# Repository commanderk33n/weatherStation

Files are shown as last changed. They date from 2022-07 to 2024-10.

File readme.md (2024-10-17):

# Weather Station NodeMCU
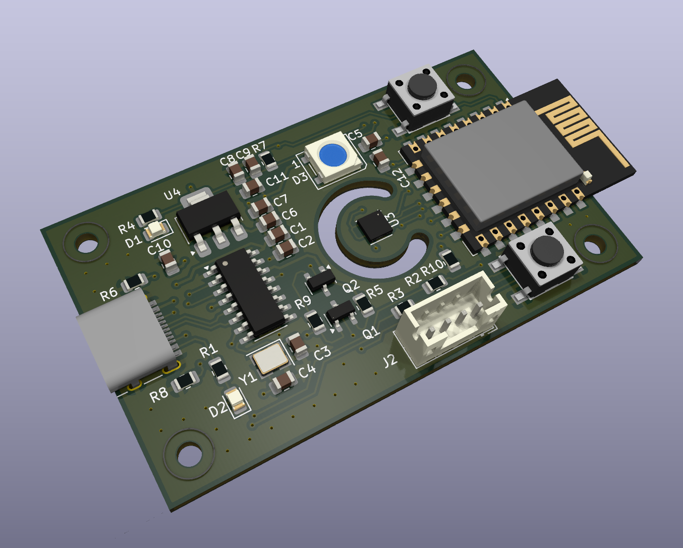
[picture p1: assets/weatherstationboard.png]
WeatherStationBoardV1.0

#### Usage:

after checkout:

- Download Arduino IDE
- Download ESP8266 Development Board and Driver File:
    - File->Preferences 'Additional Boards Manager URLs:
      - http://arduino.esp8266.com/stable/package_esp8266com_index.json
    - Download esp8266 with Boards Manager
- Install Libaries:
    - esp8266 weather
    - JSON Streaming
    - adafruit bme280
    - adafruit Unified sensor
    - oled lib from NodeMCU/lib
- Add your WIFI, Webserver and Database-Server info into weatherSationKeen.ino, esp-chart.php and post-data.php

#### Hardware used:
- NodeMCU ESP8266 (CP2102)
- GY-BME280 Sensormodul
- OLED-Display (SSH1106)
- RaspberryPi for Webserver (Nginx, MariaDB, PHP)

#### Pin Connection:
- NodeMCU ESP8266 <-----> OLED
    - 3.3V---VCC
    - GND---GND
    - D1---SCL
    - D2---SDA
- NodeMCU ESP8266<-----> BME280
    - 3.3V---VCC
    - GND---GND
    - D1---SCL
    - D2---SDA

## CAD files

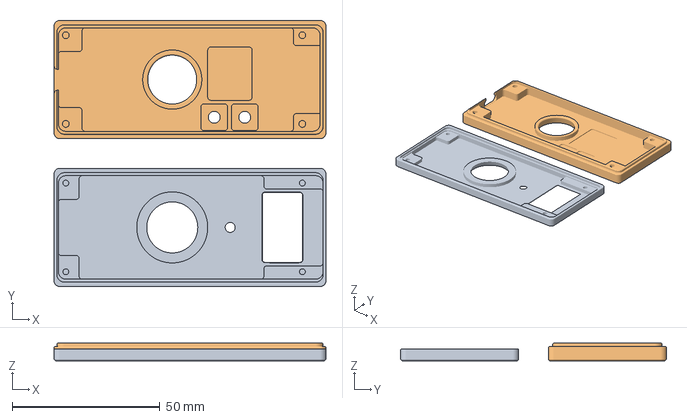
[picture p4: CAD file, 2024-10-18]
hardware/kicad/weatherStationBoard/WeatherStationBoard_REV01_CASE_BOT.3mf
92.0 x 90.0 x 6.00 mm
WeatherStationBoard_REV01_CASE_BOT.stl
WeatherStationBoard_REV01_CASE_TOP.stl

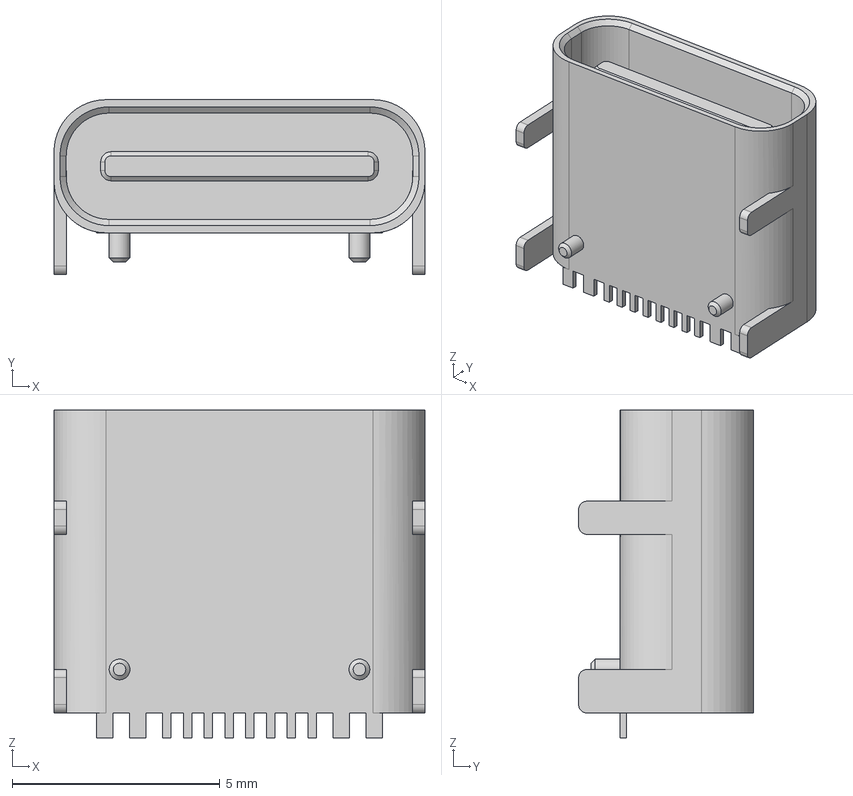
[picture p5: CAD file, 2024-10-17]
hardware/Parts/HRO TYPE-C-31-M-12/HRO TYPE-C-31-M-12.step
8.94 x 4.21 x 7.90 mm

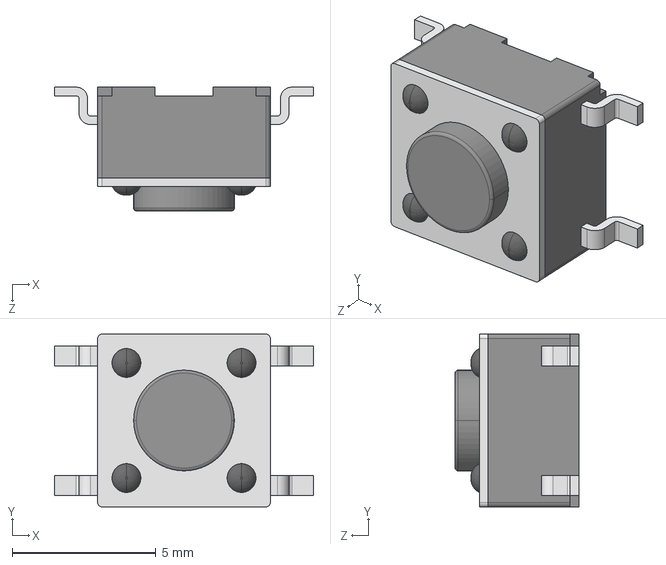
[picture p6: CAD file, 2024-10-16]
hardware/Parts/PTS645SM43SMTR92LFS/PTS645SM43SMTR92LFS.stp
9.00 x 6.00 x 4.30 mm

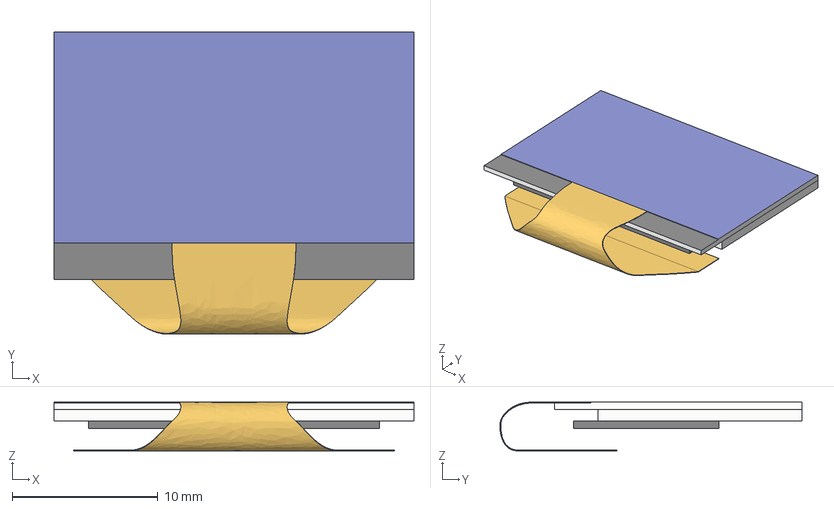
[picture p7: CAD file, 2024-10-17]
hardware/Parts/SSD1306/Unbenannt-SSD1306_Screen.step
24.7 x 20.7 x 3.35 mm
screen
screen001
screen002
flat_cable

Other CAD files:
hardware/kicad/weatherStationBoard/Gerber/weatherStationBoard-B_Silkscreen.dxf
hardware/kicad/weatherStationBoard/Gerber/weatherStationBoard-F_Silkscreen.dxf

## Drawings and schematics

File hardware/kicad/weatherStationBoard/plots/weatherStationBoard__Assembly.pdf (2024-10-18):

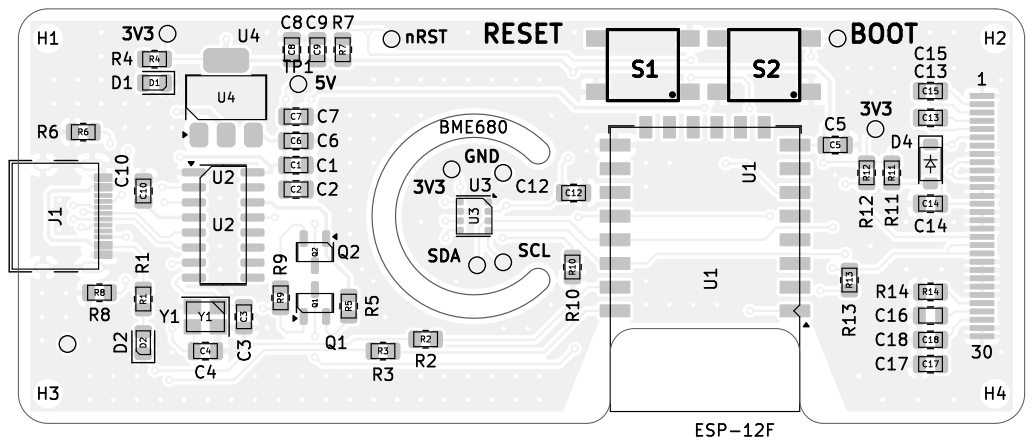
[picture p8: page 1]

Id: 1/1 Title: File: weatherStationBoard.kicad_pcb Sheet:

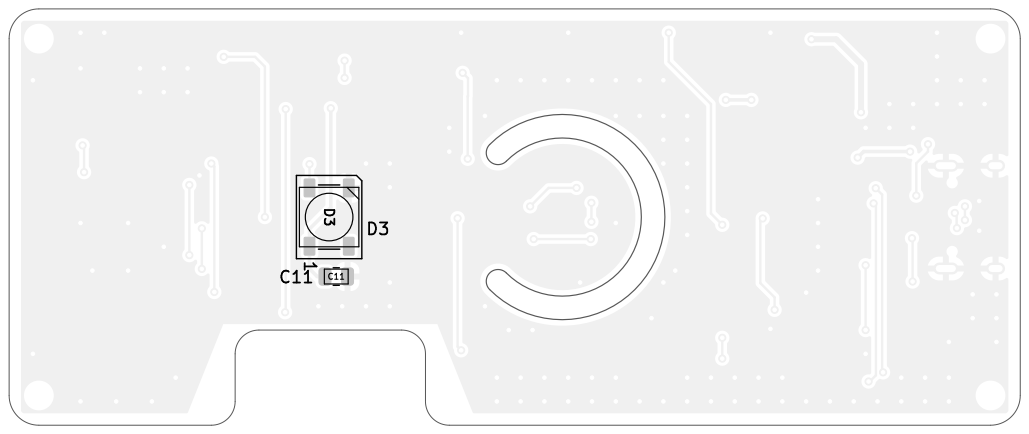
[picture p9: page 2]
D Date: KiCad; E.D.A. 8.0.6 Size: A4; Rev:

Id: 1/1 Title: File: weatherStationBoard.kicad_pcb Sheet:

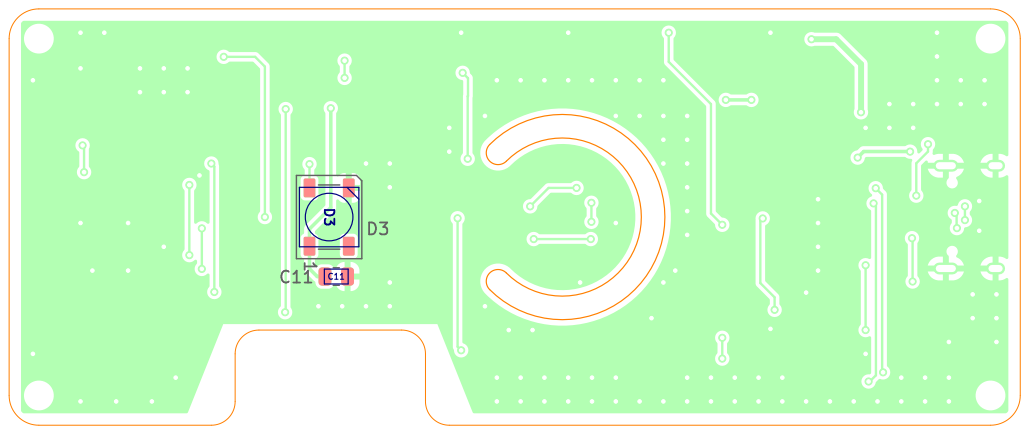
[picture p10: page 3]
D Date: KiCad; E.D.A. 8.0.6 Size: A4; Rev:

Id: 1/1 Title: File: weatherStationBoard.kicad_pcb Sheet:

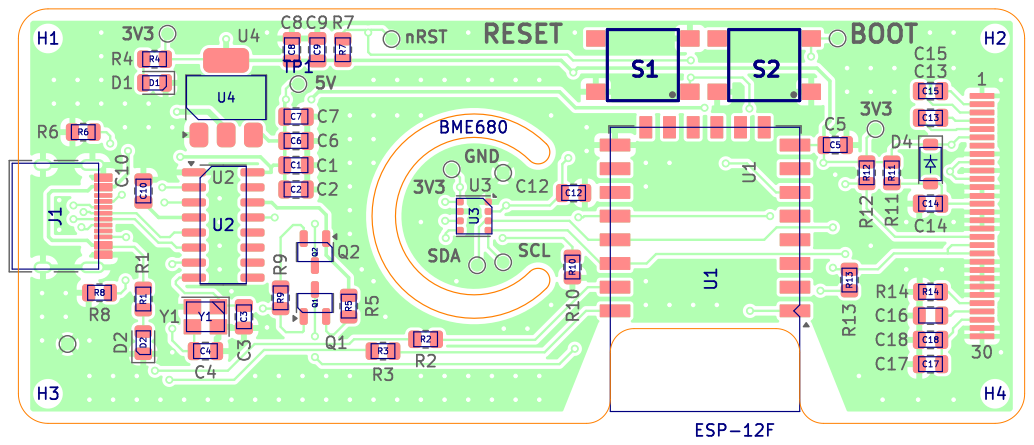
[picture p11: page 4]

Id: 1/1 Title: File: weatherStationBoard.kicad_pcb Sheet:

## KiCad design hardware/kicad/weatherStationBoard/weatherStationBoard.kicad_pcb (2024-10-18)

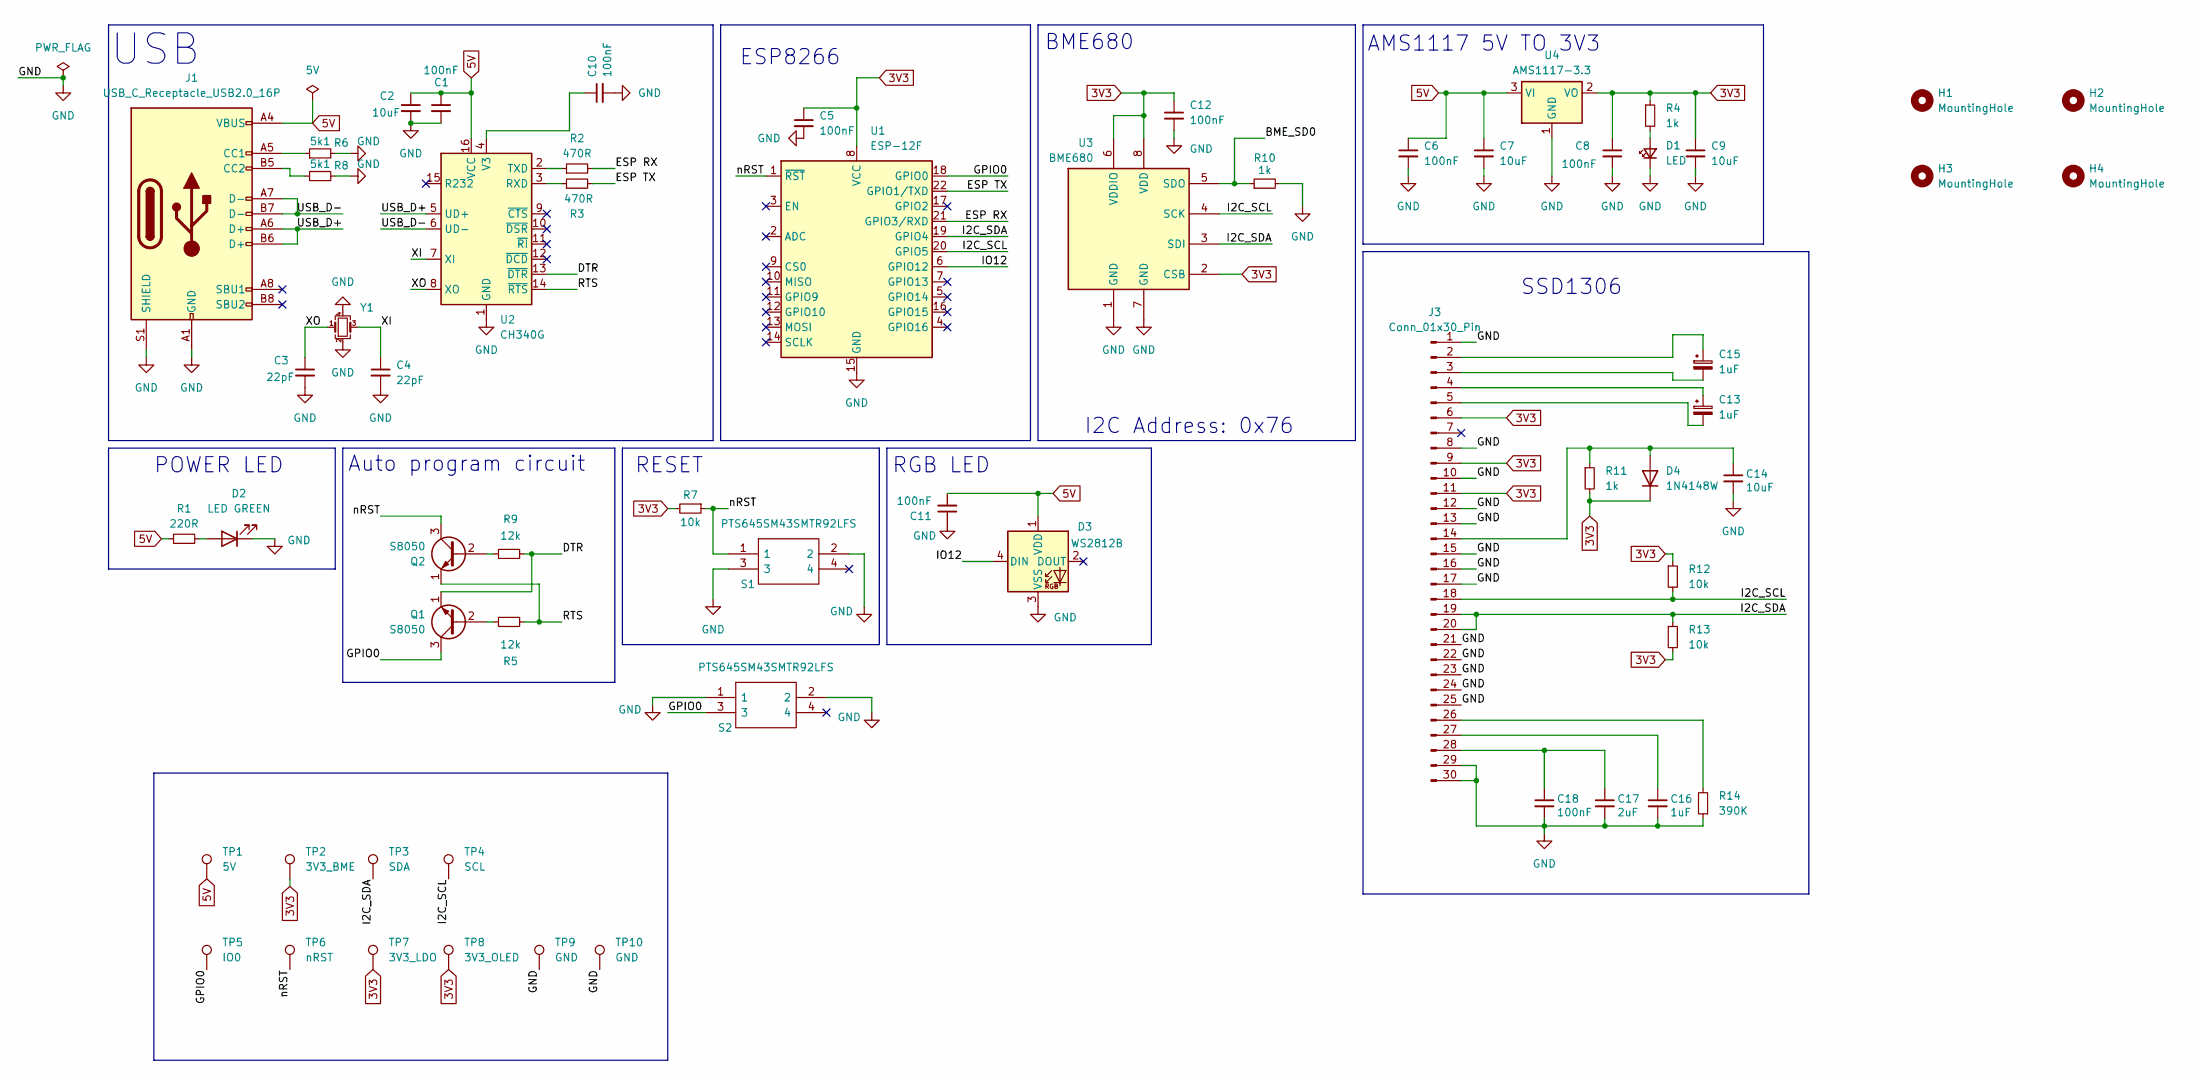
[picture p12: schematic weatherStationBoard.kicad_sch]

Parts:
C1, C5, C6, C8, C10, C11, C12, C18: 100nF; C_0805_2012Metric
C2, C7, C9, C14: 10uF; C_0805_2012Metric
C3, C4: 22pF; C_0805_2012Metric
C13, C15, C16: 1uF; C_0805_2012Metric
C17: 2uF; C_0805_2012Metric
D1: LED; LED_0805_2012Metric
D2: LED GREEN; LED_0805_2012Metric
D3: WS2812B; LED_WS2812B_PLCC4_5.0x5.0mm_P3.2mm
D4: 1N4148W; D_SOD-123
H1, H2, H3, H4: MountingHole; MountingHole_2.2mm_M2
J1: USB_C_Receptacle_USB2.0_16P; USB_C_Receptacle_HRO_TYPE-C-31-M-12
J3: Conn_01x30_Pin; SSD1306_ribbon
Q1, Q2: S8050; SOT-23-3
R1: 220R; R_0805_2012Metric
R2, R3: 470R; R_0805_2012Metric
R4, R10, R11: 1k; R_0805_2012Metric
R5, R9: 12k; R_0805_2012Metric
R6, R8: 5k1; R_0805_2012Metric
R7, R12, R13: 10k; R_0805_2012Metric
R14: 390K; R_0805_2012Metric
S1, S2: PTS645SM43SMTR92LFS; PTS645_SMT_; Manufacturer_Part_Number PTS645SM43SMTR92LFS; Mouser Part Number 611-PTS645SM43SMTR92
TP1: 5V; TestPoint_Pad_D1.0mm
TP2: 3V3_BME; TestPoint_Pad_D1.0mm
TP3: SDA; TestPoint_Pad_D1.0mm
TP4: SCL; TestPoint_Pad_D1.0mm
TP5: IO0; TestPoint_Pad_D1.0mm
TP6: nRST; TestPoint_Pad_D1.0mm
TP7: 3V3_LDO; TestPoint_Pad_D1.0mm
TP8: 3V3_OLED; TestPoint_Pad_D1.0mm
TP9, TP10: GND; TestPoint_Pad_D1.0mm
U1: ESP-12F; ESP-12E
U2: CH340G; SOIC-16_3.9x9.9mm_P1.27mm
U3: BME680; Bosch_LGA-8_3x3mm_P0.8mm_ClockwisePinNumbering
U4: AMS1117-3.3; SOT-223-3_TabPin2
Y1: Crystal_GND24_Small; Crystal_SMD_3225-4Pin_3.2x2.5mm

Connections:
3V3: C5.1, C8.1, C9.1, C12.1, D4.1 (K), J3.6, J3.9, J3.11, R4.1, R7.2, R11.2, R12.1, R13.2, TP2.1, TP7.1, TP8.1, U1.8 (VCC), U3.2 (CSB), U3.6 (VDDIO), U3.8 (VDD), U4.2 (VO)
5V: C1.1, C2.1, C6.1, C7.1, C11.2, D3.1 (VDD), J1.A4 (VBUS), J1.A9 (VBUS), J1.B4 (VBUS), J1.B9 (VBUS), R1.1, TP1.1, U2.16 (VCC), U4.3 (VI)
/BME_SD0: R10.1, U3.5 (SDO)
/DTR: Q1.1 (E), R9.2, U2.13 (~DTR)
/ESP RX: R2.2, U1.21 (GPIO3/RXD)
/ESP TX: R3.2, U1.22 (GPIO1/TXD)
/GPIO0: Q1.3 (C), S2.3, TP5.1, U1.18 (GPIO0)
/I2C_SCL: J3.18, R12.2, TP4.1, U1.20 (GPIO5), U3.4 (SCK)
/I2C_SDA: J3.19, J3.20, R13.1, TP3.1, U1.19 (GPIO4), U3.3 (SDI)
/IO12: D3.4 (DIN), U1.6 (GPIO12)
/RTS: Q2.1 (E), R5.2, U2.14 (~RTS)
/USB_D+: J1.A6 (D+), J1.B6 (D+), U2.5 (UD+)
/USB_D-: J1.A7 (D-), J1.B7 (D-), U2.6 (UD-)
/XI: C4.1, U2.7 (XI), Y1.3
/XO: C3.1, U2.8 (XO), Y1.1
/nRST: Q2.3 (C), R7.1, S1.1, TP6.1, U1.1 (~RST)
GND: C1.2, C2.2, C3.2, C4.2, C5.2, C6.2, C7.2, C8.2, C9.2, C10.2, C11.1, C12.2, C14.2, C16.2, C17.2, C18.2, D1.1 (K), D2.1 (K), D3.3 (VSS), J1.A1 (GND), J1.A12 (GND), J1.B1 (GND), J1.B12 (GND), J1.S1 (SHIELD), J3.1, J3.8, J3.10, J3.12, J3.13, J3.15, J3.16, J3.17, J3.21, J3.22, J3.23, J3.24, J3.25, J3.29, J3.30, R6.2, R8.2, R10.2, R14.1, S1.2, S1.3, S2.1, S2.2, TP9.1, TP10.1, U1.15 (GND), U2.1 (GND), U3.1 (GND), U3.7 (GND), U4.1 (GND), Y1.2, Y1.4
unnamed: D1.2 (A), R4.2
unnamed: D2.2 (A), R1.2
unnamed: C14.1, D4.2 (A), J3.14, R11.1
unnamed: J1.A5 (CC1), R6.1
unnamed: J1.B5 (CC2), R8.1
unnamed: C15.1, J3.2
unnamed: C15.2, J3.3
unnamed: C13.1, J3.4
unnamed: C13.2, J3.5
unnamed: J3.26, R14.2
unnamed: C16.1, J3.27
unnamed: C17.1, C18.1, J3.28
unnamed: Q1.2 (B), R5.1
unnamed: Q2.2 (B), R9.1
unnamed: R3.1, U2.3 (RXD)
unnamed: R2.1, U2.2 (TXD)
unnamed: C10.1, U2.4 (V3)

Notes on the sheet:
I2C Address: 0x76
SSD1306
BME680
RGB LED
RESET
ESP8266
Auto program circuit
USB
AMS1117 5V TO 3V3
POWER LED

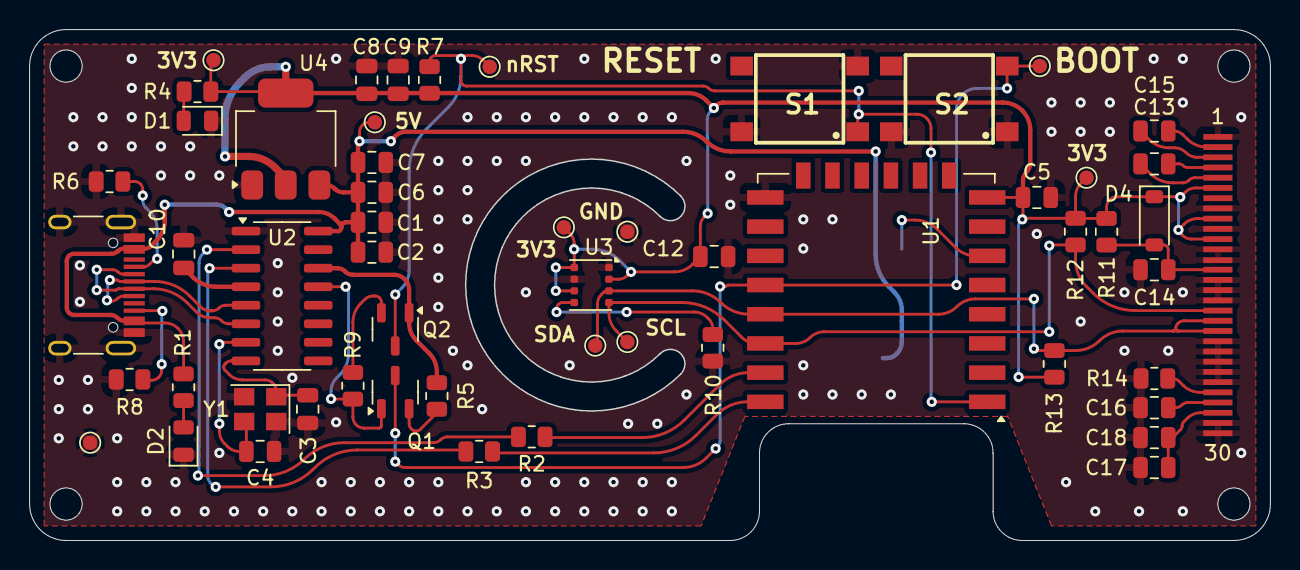
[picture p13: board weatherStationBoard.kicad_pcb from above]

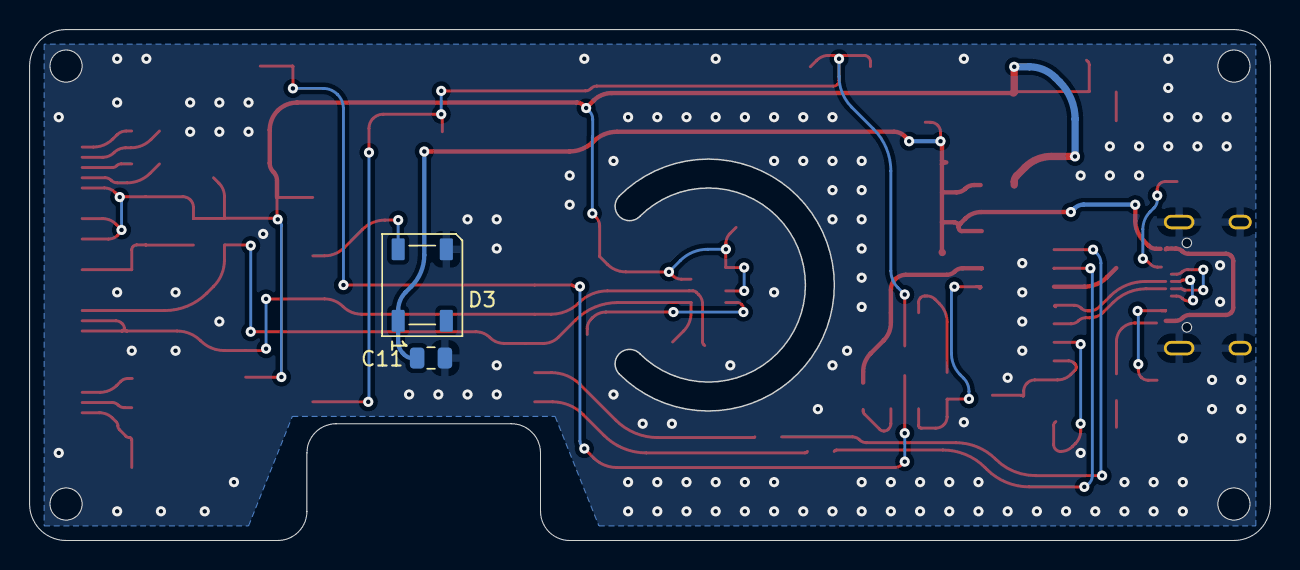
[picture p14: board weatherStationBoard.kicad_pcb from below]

Board: 4 copper layers, 85.0 x 35.0 mm, 61 parts (2 on the bottom side), 34 nets.

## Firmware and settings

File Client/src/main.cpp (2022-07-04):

/**
 * Keen's WeatherStation for NodeMCU
 * Display: SH1106Sensor: BME280
 * OpenWeatherMap API + http POST data to webserver
 */

#include <ESPWiFi.h>
#include <ESPHTTPClient.h>
#include <JsonListener.h>
#include <Adafruit_Sensor.h>
#include <Adafruit_BME280.h>
// time
#include <time.h>      // time() ctime()
#include <sys/time.h>  // struct timeval
#include <coredecls.h> // settimeofday_cb()
//#include "SSD1306Wire.h"
#include <SH1106Wire.h>
#include <OLEDDisplayUi.h>
#include <Wire.h>
#include <OpenWeatherMapCurrent.h>
#include <OpenWeatherMapForecast.h>
#include <WeatherStationFonts.h>
#include <WeatherStationImages.h>

// Create the Lightsensor instance
#define BME_SCK 13
#define BME_MISO 12
#define BME_MOSI 11
#define BME_CS 10
#define SEALEVELPRESSURE_HPA (1013.25)
Adafruit_BME280 bme; // I2C
// DHTesp dht;
/***************************
   Begin Settings
 **************************/

// WIFI
const char *WIFI_SSID = "XXXX";
const char *WIFI_PWD = "XXXX";

// HTTP
const char *serverName = "XXXX";
String apiKeyValue = "XXXX";

#define TZ 0      // (utc+) TZ in hours
#define DST_MN 60 // use 60mn for summer time in some countries

// Setup
const int UPDATE_INTERVAL_SECS = 20 * 60; // Update every 20 minutes
const int POST_DATA_INTERVAL = 10 * 60;   // Send data every 20 min to server

unsigned long delayTime;
// Display Settings
const int I2C_DISPLAY_ADDRESS = 0x3c;
#if defined(ESP8266)
const int SDA_PIN = D2;
const int SDC_PIN = D1;
const int DH1 = D5;
#else
const int SDA_PIN = 4; // D3;
const int SDC_PIN = 5; // D4;
const int DH1 = 14;
#endif
// OpenWeatherMap Settings
// Sign up here to get an API key:
// https://docs.thingpulse.com/how-tos/openweathermap-key/
String OPEN_WEATHER_MAP_APP_ID = "XXXX";
/*
  Go to https://openweathermap.org/find?q= and search for a location. Go through the
  result set and select the entry closest to the actual location you want to display
  data for. It'll be a URL like https://openweathermap.org/city/2657896. The number
  at the end is what you assign to the constant below.
*/
String OPEN_WEATHER_MAP_LOCATION_ID = "XXXX";

// Pick a language code from this list:
// Arabic - ar, Bulgarian - bg, Catalan - ca, Czech - cz, German - de, Greek - el,
// English - en, Persian (Farsi) - fa, Finnish - fi, French - fr, Galician - gl,
// Croatian - hr, Hungarian - hu, Italian - it, Japanese - ja, Korean - kr,
// Latvian - la, Lithuanian - lt, Macedonian - mk, Dutch - nl, Polish - pl,
// Portuguese - pt, Romanian - ro, Russian - ru, Swedish - se, Slovak - sk,
// Slovenian - sl, Spanish - es, Turkish - tr, Ukrainian - ua, Vietnamese - vi,
// Chinese Simplified - zh_cn, Chinese Traditional - zh_tw.
String OPEN_WEATHER_MAP_LANGUAGE = "de";
const uint8_t MAX_FORECASTS = 4;

const boolean IS_METRIC = true;

// Adjust according to your language
const String WDAY_NAMES[] = {"SUN", "MON", "TUE", "WED", "THU", "FRI", "SAT"};
const String MONTH_NAMES[] = {"JAN", "FEB", "MAR", "APR", "MAY", "JUN", "JUL", "AUG", "SEP", "OCT", "NOV", "DEC"};

/***************************
   End Settings
 **************************/
// Initialize the oled display for address 0x3c
// sda-pin=14 and sdc-pin=12
// SSD1306Wire     display(I2C_DISPLAY_ADDRESS, SDA_PIN, SDC_PIN);
SH1106Wire display(I2C_DISPLAY_ADDRESS, SDA_PIN, SDC_PIN);
OLEDDisplayUi ui(&display);

OpenWeatherMapCurrentData currentWeather;
OpenWeatherMapCurrent currentWeatherClient;

OpenWeatherMapForecastData forecasts[MAX_FORECASTS];
OpenWeatherMapForecast forecastClient;

#define TZ_MN ((TZ)*60)
#define TZ_SEC ((TZ)*3600)
#define DST_SEC ((DST_MN)*60)
time_t now;

// flag changed in the ticker function every 10 minutes
bool readyForWeatherUpdate = false;

String lastUpdate = "--";

long timeSinceLastWUpdate = 0;
long timeSinceLastPOST = 0;

// declaring prototypes
void drawProgress(OLEDDisplay *display, int percentage, String label);
void updateData(OLEDDisplay *display);
void drawBME(OLEDDisplay *display, OLEDDisplayUiState *state, int16_t x, int16_t y);
void drawDateTime(OLEDDisplay *display, OLEDDisplayUiState *state, int16_t x, int16_t y);
void drawCurrentWeather(OLEDDisplay *display, OLEDDisplayUiState *state, int16_t x, int16_t y);
void drawForecast(OLEDDisplay *display, OLEDDisplayUiState *state, int16_t x, int16_t y);
void drawForecastDetails(OLEDDisplay *display, int x, int y, int dayIndex);
void drawHeaderOverlay(OLEDDisplay *display, OLEDDisplayUiState *state);
void setReadyForWeatherUpdate();
void makePOST();

// Add frames
// this array keeps function pointers to all frames
// frames are the single views that slide from right to left
FrameCallback frames[] = {drawDateTime, drawCurrentWeather, drawForecast, drawBME};
int numberOfFrames = 4;

OverlayCallback overlays[] = {drawHeaderOverlay};
int numberOfOverlays = 1;

void setup()
{
  Serial.begin(115200);
  Serial.println();
  Serial.println("BME280 test");
  bool status;
  status = bme.begin(0x76);
  if (!status)
  {
    Serial.println("Could not find a valid BME280 sensor, check wiring!");
  }
  // initialize dispaly
  display.init();
  display.clear();
  display.display();

  display.flipScreenVertically();
  display.setFont(ArialMT_Plain_10);
  display.setTextAlignment(TEXT_ALIGN_CENTER);
  display.setContrast(255);

  WiFi.begin(WIFI_SSID, WIFI_PWD);
  WiFi.mode(WIFI_STA);

  int counter = 0;
  while (WiFi.status() != WL_CONNECTED)
  {
    delay(500);
    Serial.print(".");
    display.clear();
    display.drawString(64, 10, "Connecting to WiFi");
    display.drawXbm(40, 30, 8, 8, counter % 3 == 0 ? activeSymbole : inactiveSymbole);
    display.drawXbm(54, 30, 8, 8, counter % 3 == 1 ? activeSymbole : inactiveSymbole);
    display.drawXbm(68, 30, 8, 8, counter % 3 == 2 ? activeSymbole : inactiveSymbole);
    display.display();

    counter++;
  }
  Serial.println("");
  Serial.print("Connected to WiFi network with IP Address: ");
  Serial.println(WiFi.localIP());

  // Get time from network time service
  configTime(TZ_SEC, DST_SEC, "pool.ntp.org");

  ui.setTargetFPS(30);

  ui.setActiveSymbol(activeSymbole);
  ui.setInactiveSymbol(inactiveSymbole);

  // You can change this to
  // TOP, LEFT, BOTTOM, RIGHT
  ui.setIndicatorPosition(BOTTOM);

  // Defines where the first frame is located in the bar.
  ui.setIndicatorDirection(LEFT_RIGHT);

  // You can change the transition that is used
  // SLIDE_LEFT, SLIDE_RIGHT, SLIDE_TOP, SLIDE_DOWN
  ui.setFrameAnimation(SLIDE_LEFT);

  ui.setFrames(frames, numberOfFrames);

  ui.setOverlays(overlays, numberOfOverlays);

  // Inital UI takes care of initalising the display too.
  ui.init();

  Serial.println("");

  updateData(&display);
  // makePOST();
}

void loop()
{
  if (millis() - timeSinceLastWUpdate > (1000L * UPDATE_INTERVAL_SECS))
  {
    setReadyForWeatherUpdate();
    timeSinceLastWUpdate = millis();
  }

  if (readyForWeatherUpdate && ui.getUiState()->frameState == FIXED)
  {
    updateData(&display);
  }

  if (millis() - timeSinceLastPOST > (1000L * POST_DATA_INTERVAL))
  {
    // makePOST();
    timeSinceLastPOST = millis();
  }

  int remainingTimeBudget = ui.update();

  if (remainingTimeBudget > 0)
  {
    // You can do some work here
    // Don't do stuff if you are below your
    // time budget.
    delay(remainingTimeBudget);
  }
}

void makePOST()
{
  // Check WiFi connection status
  if (WiFi.status() == WL_CONNECTED)
  {
    HTTPClient http;
    WiFiClient client;

    // Your Domain name with URL path or IP address with path
    http.begin(client, serverName);

    // Specify content-type header
    http.addHeader("Content-Type", "application/x-www-form-urlencoded");

    // Prepare your HTTP POST request data
    String httpRequestData = "api_key=" + apiKeyValue + "&value1=" + String(bme.readTemperature()) + "&value2=" + String(bme.readHumidity()) + "&value3=" + String(bme.readPressure() / 100.0F) + "";
    Serial.print("httpRequestData: ");
    Serial.println(httpRequestData);

    // You can comment the httpRequestData variable above
    // then, use the httpRequestData variable below (for testing purposes without the BME280 sensor)
    // String httpRequestData = "api_key=tPmAT5Ab3j7F9&value1=24.75&value2=49.54&value3=1005.14";

    // Send HTTP POST request
    int httpResponseCode = http.POST(httpRequestData);

    // If you need an HTTP request with a content type: text/plain
    // http.addHeader("Content-Type", "text/plain");
    // int httpResponseCode = http.POST("Hello, World!");

    // If you need an HTTP request with a content type: application/json, use the following:
    // http.addHeader("Content-Type", "application/json");
    // int httpResponseCode = http.POST("{\"value1\":\"19\",\"value2\":\"67\",\"value3\":\"78\"}");

    if (httpResponseCode > 0)
    {
      Serial.print("HTTP Response code: ");
      Serial.println(httpResponseCode);
    }
    else
    {
      Serial.print("Error code: ");
      Serial.println(httpResponseCode);
    }
    // Free resources
    http.end();
  }
  else
  {
    Serial.println("WiFi Disconnected");
  }
}

void drawProgress(OLEDDisplay *display, int percentage, String label)
{
  display->clear();
  display->flipScreenVertically();
  display->setTextAlignment(TEXT_ALIGN_CENTER);
  display->setFont(ArialMT_Plain_10);
  display->drawString(64, 10, label);
  display->drawProgressBar(2, 28, 124, 10, percentage);
  display->display();
}

void updateData(OLEDDisplay *display)
{
  drawProgress(display, 10, "Updating time...");
  drawProgress(display, 30, "Updating weather...");
  currentWeatherClient.setMetric(IS_METRIC);
  currentWeatherClient.setLanguage(OPEN_WEATHER_MAP_LANGUAGE);
  currentWeatherClient.updateCurrentById(&currentWeather, OPEN_WEATHER_MAP_APP_ID, OPEN_WEATHER_MAP_LOCATION_ID);
  drawProgress(display, 50, "Updating forecasts...");
  forecastClient.setMetric(IS_METRIC);
  forecastClient.setLanguage(OPEN_WEATHER_MAP_LANGUAGE);
  uint8_t allowedHours[] = {12};
  forecastClient.setAllowedHours(allowedHours, sizeof(allowedHours));
  forecastClient.updateForecastsById(forecasts, OPEN_WEATHER_MAP_APP_ID, OPEN_WEATHER_MAP_LOCATION_ID, MAX_FORECASTS);

  readyForWeatherUpdate = false;
  drawProgress(display, 100, "Done...");
  delay(1000);
}

void drawBME(OLEDDisplay *display, OLEDDisplayUiState *state, int16_t x, int16_t y)
{
  float temp1 = bme.readTemperature();
  float pres1 = bme.readPressure() / 100.0F;
  float humi1 = bme.readHumidity();
  delay(delayTime);
  display->setTextAlignment(TEXT_ALIGN_CENTER);
  display->setFont(ArialMT_Plain_16);
  String humi = (IS_METRIC ? "H:" : "H:") + String(humi1, 1) + (IS_METRIC ? "%" : "%");
  display->drawString(64 + x, y, humi);
  display->setTextAlignment(TEXT_ALIGN_CENTER);
  display->setFont(ArialMT_Plain_16);
  String temp = (IS_METRIC ? " T:" : "T:") + String(temp1, 1) + (IS_METRIC ? "°C" : "°F");
  display->drawString(64 + x, 15 + y, temp);
  display->setTextAlignment(TEXT_ALIGN_CENTER);
  display->setFont(ArialMT_Plain_16);
  String pres = (IS_METRIC ? " P:" : "P:") + String(pres1, 1) + (IS_METRIC ? "hPa" : "hPa");
  display->drawString(64 + x, 30 + y, pres);
}

void drawDateTime(OLEDDisplay *display, OLEDDisplayUiState *state, int16_t x, int16_t y)
{
  now = time(nullptr);
  struct tm *timeInfo;
  timeInfo = localtime(&now);
  char buff[16];

  display->setTextAlignment(TEXT_ALIGN_CENTER);
  display->setFont(ArialMT_Plain_10);
  String date = WDAY_NAMES[timeInfo->tm_wday];

  sprintf_P(buff, PSTR("%s, %02d/%02d/%04d"), WDAY_NAMES[timeInfo->tm_wday].c_str(), timeInfo->tm_mday, timeInfo->tm_mon + 1, timeInfo->tm_year + 1900);
  display->drawString(64 + x, 5 + y, String(buff));
  display->setFont(ArialMT_Plain_24);

  sprintf_P(buff, PSTR("%02d:%02d:%02d"), timeInfo->tm_hour, timeInfo->tm_min, timeInfo->tm_sec);
  display->drawString(64 + x, 15 + y, String(buff));
  display->setTextAlignment(TEXT_ALIGN_LEFT);
}

void drawCurrentWeather(OLEDDisplay *display, OLEDDisplayUiState *state, int16_t x, int16_t y)
{
  display->setFont(ArialMT_Plain_10);
  display->setTextAlignment(TEXT_ALIGN_CENTER);
  display->drawString(64 + x, 38 + y, currentWeather.description);

  display->setFont(ArialMT_Plain_24);
  display->setTextAlignment(TEXT_ALIGN_LEFT);
  String temp = String(currentWeather.temp, 1) + (IS_METRIC ? "°C" : "°F");
  display->drawString(60 + x, 5 + y, temp);

  display->setFont(Meteocons_Plain_36);
  display->setTextAlignment(TEXT_ALIGN_CENTER);
  display->drawString(32 + x, 0 + y, currentWeather.iconMeteoCon);
}

void drawForecast(OLEDDisplay *display, OLEDDisplayUiState *state, int16_t x, int16_t y)
{
  drawForecastDetails(display, x, y, 0);
  drawForecastDetails(display, x + 44, y, 1);
  drawForecastDetails(display, x + 88, y, 2);
}

void drawForecastDetails(OLEDDisplay *display, int x, int y, int dayIndex)
{
  time_t observationTimestamp = forecasts[dayIndex].observationTime;
  struct tm *timeInfo;
  timeInfo = localtime(&observationTimestamp);
  display->setTextAlignment(TEXT_ALIGN_CENTER);
  display->setFont(ArialMT_Plain_10);
  display->drawString(x + 20, y, WDAY_NAMES[timeInfo->tm_wday]);

  display->setFont(Meteocons_Plain_21);
  display->drawString(x + 20, y + 12, forecasts[dayIndex].iconMeteoCon);
  String temp = String(forecasts[dayIndex].temp, 0) + (IS_METRIC ? "°C" : "°F");
  display->setFont(ArialMT_Plain_10);
  display->drawString(x + 20, y + 34, temp);
  display->setTextAlignment(TEXT_ALIGN_LEFT);
}

void drawHeaderOverlay(OLEDDisplay *display, OLEDDisplayUiState *state)
{
  now = time(nullptr);
  struct tm *timeInfo;
  timeInfo = localtime(&now);
  char buff[14];
  sprintf_P(buff, PSTR("%02d:%02d"), timeInfo->tm_hour, timeInfo->tm_min);

  display->setColor(WHITE);
  display->setFont(ArialMT_Plain_10);
  display->setTextAlignment(TEXT_ALIGN_LEFT);
  display->drawString(0, 54, String(buff));
  display->setTextAlignment(TEXT_ALIGN_RIGHT);
  String temp = String(currentWeather.temp, 1) + (IS_METRIC ? "°C" : "°F");
  display->drawString(128, 54, temp);
  display->drawHorizontalLine(0, 52, 128);
}

void setReadyForWeatherUpdate()
{
  Serial.println("Setting readyForUpdate to true");
  readyForWeatherUpdate = true;
}

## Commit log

2024-10-15 Hardware files
    [weatherStationBoard.kicad_pcb, weatherStationBoard.kicad_sch]
2024-10-15 Node mcu schematic
2024-10-15 ignore local backups of kicad
2024-10-15 PCB Simple LED Circuit With Usb-C
    [weatherStationBoard.kicad_pcb, weatherStationBoard.kicad_sch]
2024-10-15 power, 5vto3v, usb to serial
    [weatherStationBoard.kicad_pcb, weatherStationBoard.kicad_sch]
2024-10-15 PCB updated
    [weatherStationBoard.kicad_pcb, weatherStationBoard.kicad_sch]
2024-10-16 Pushbutton files
    [weatherStationBoard.kicad_sch]
2024-10-16 3D Model of Pushbutton
    [PTS645SM43SMTR92LFS.stp]
2024-10-16 Updated usb connector
    [weatherStationBoard.kicad_pcb, weatherStationBoard.kicad_sch]
2024-10-16 board design prototype no periphery
    [weatherStationBoard.kicad_pcb, weatherStationBoard.kicad_sch]
2024-10-17 Added BME680 Display-Connector and Mounting holes - 3D model of USB connector and Readme assets
    [HRO TYPE-C-31-M-12.step, weatherStationBoard.kicad_pcb, weatherStationBoard.kicad_sch]
2024-10-17 Testpoints added
    [weatherStationBoard.kicad_pcb, weatherStationBoard.kicad_sch]
2024-10-17 REV1 WeatherStationBoard
    [weatherStationBoard.kicad_pcb, weatherStationBoard.kicad_sch]
2024-10-18 Gerberfiles and final Case model
    [JLCPCB.kicad_pcb, JLCPCB.kicad_sch, WeatherStationBoard_REV01_CASE_BOT.3mf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]
2024-10-18 improved step model and silkscreen export
    [weatherStationBoard-B_Silkscreen.dxf, weatherStationBoard-F_Silkscreen.dxf]
